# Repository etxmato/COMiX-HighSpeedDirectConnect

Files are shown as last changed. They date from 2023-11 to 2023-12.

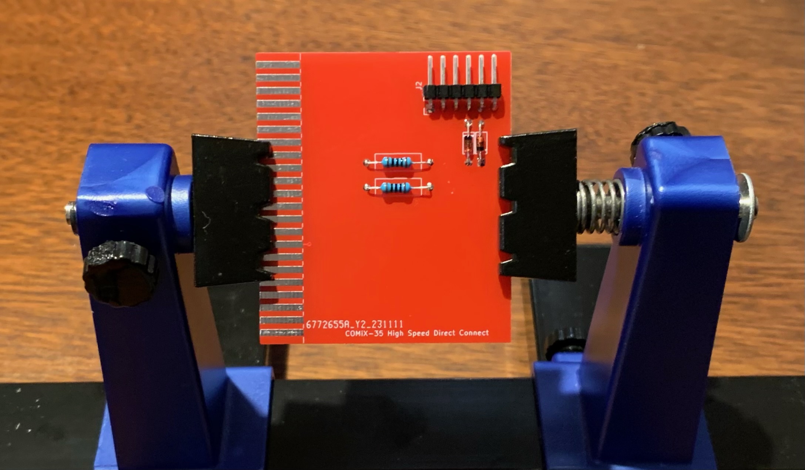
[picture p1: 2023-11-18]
images/HSDC Build.jpeg

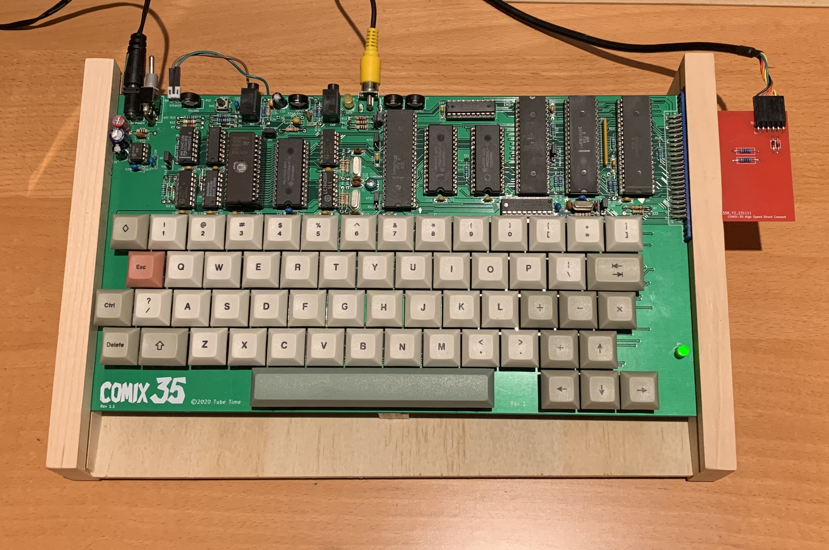
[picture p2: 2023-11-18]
images/COMiX and HSDC Adapter.jpeg

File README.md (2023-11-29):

# COMiX High Speed Direct Connect

With the High Speed Direct Connect HW & SW for the COMiX it is possible to transfer files between a modern PC and a COMiX. On the COMiX, PSAVE and PLOAD commands can be used with speeds of 9600 baud on a 2.8 Mhz CPU and 19200 baud on a 6 Mhz CPU.

Overview of the HSDC solution: 

Comix Direct Connect

Manual and all detailed information is available on our [Wiki](https://github.com/etxmato/COMiX-HighSpeedDirectConnect/wiki)

Andrew Wasson, 
Hank Riley,
Marcel van Tongeren

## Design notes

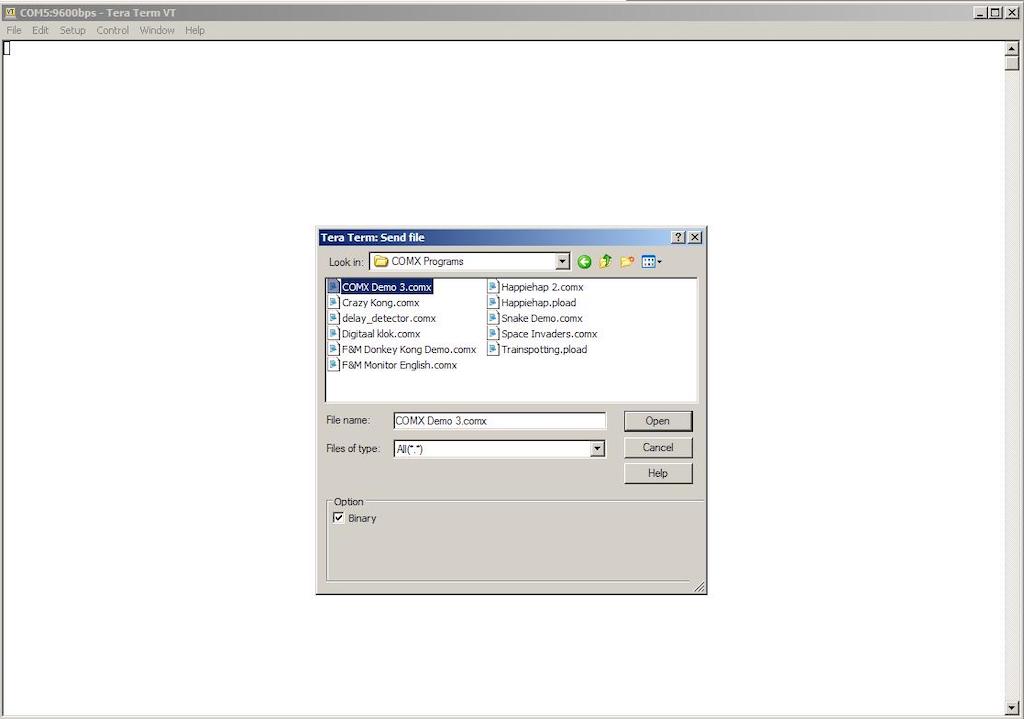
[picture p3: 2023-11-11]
images/teraterm send file as binary COMiX in PLOAD state.jpg

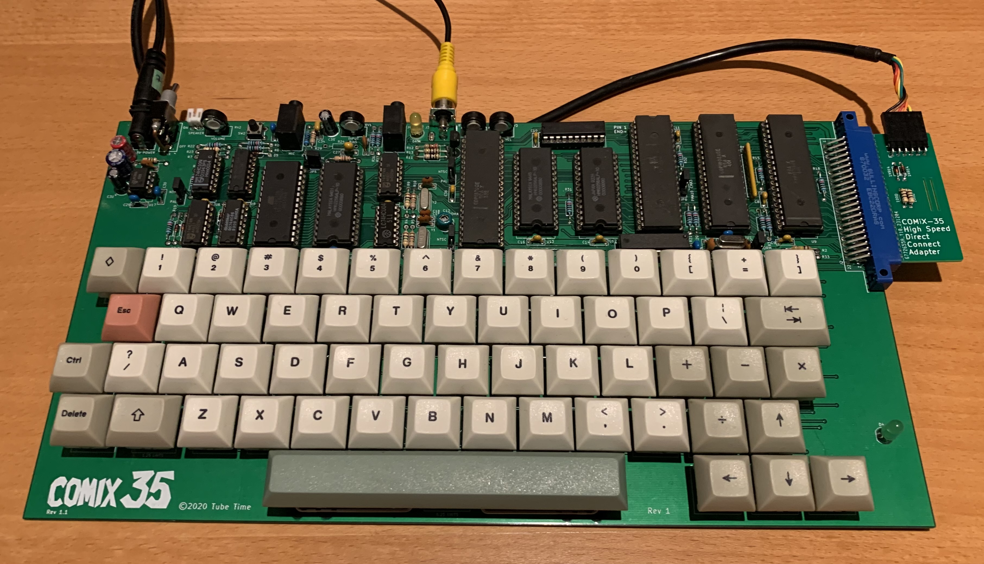
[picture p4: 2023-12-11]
images/IMG_9994-A.jpeg

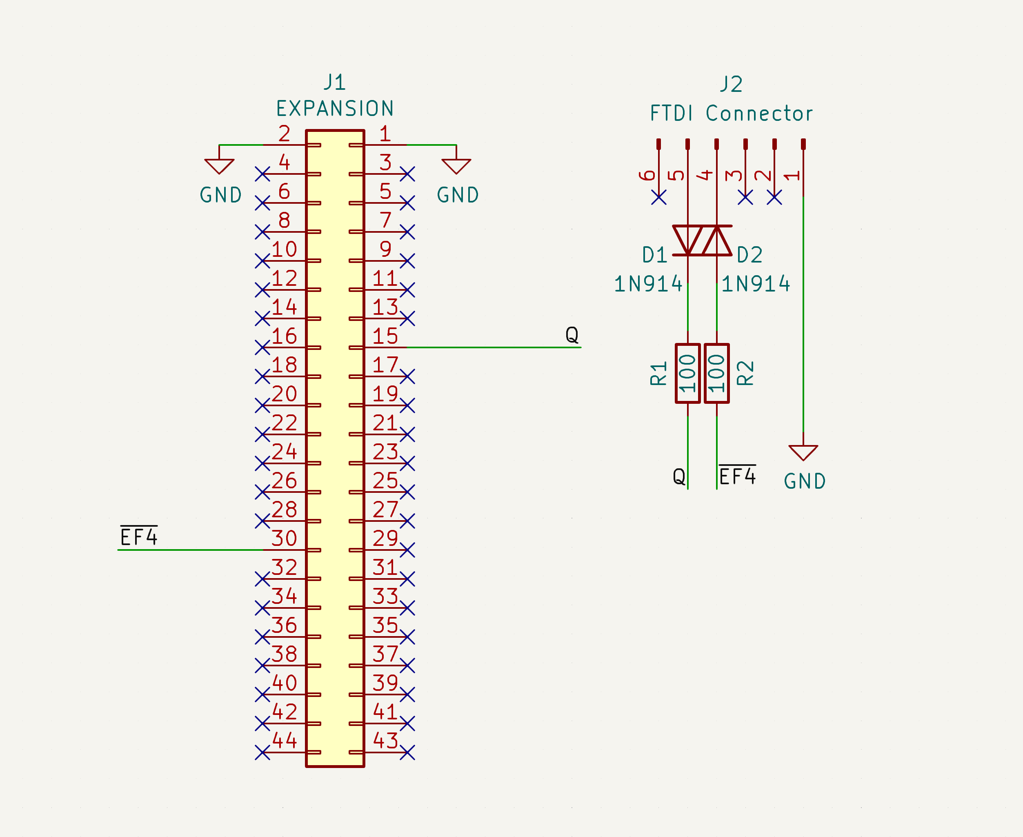
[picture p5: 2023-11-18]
images/COMiX FTDI Adapter Circuit.png

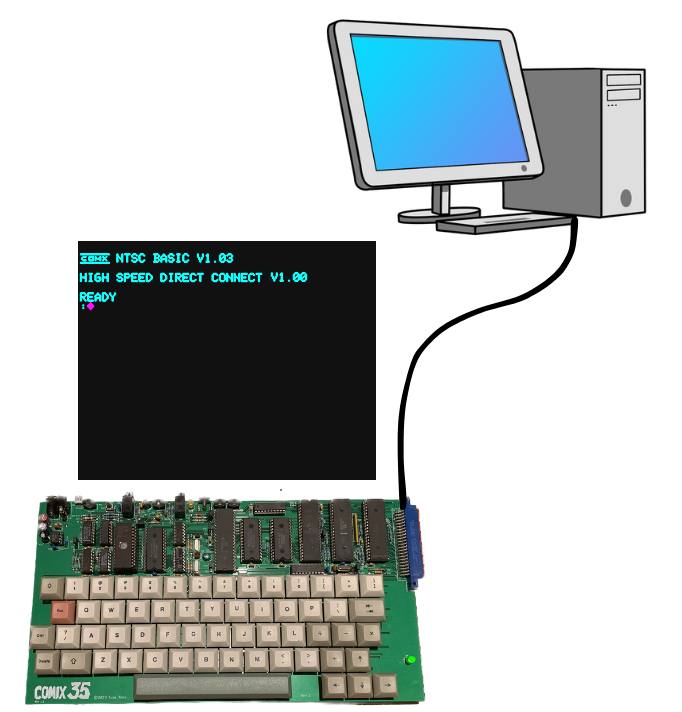
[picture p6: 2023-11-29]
images/overall connection graphic A.jpg

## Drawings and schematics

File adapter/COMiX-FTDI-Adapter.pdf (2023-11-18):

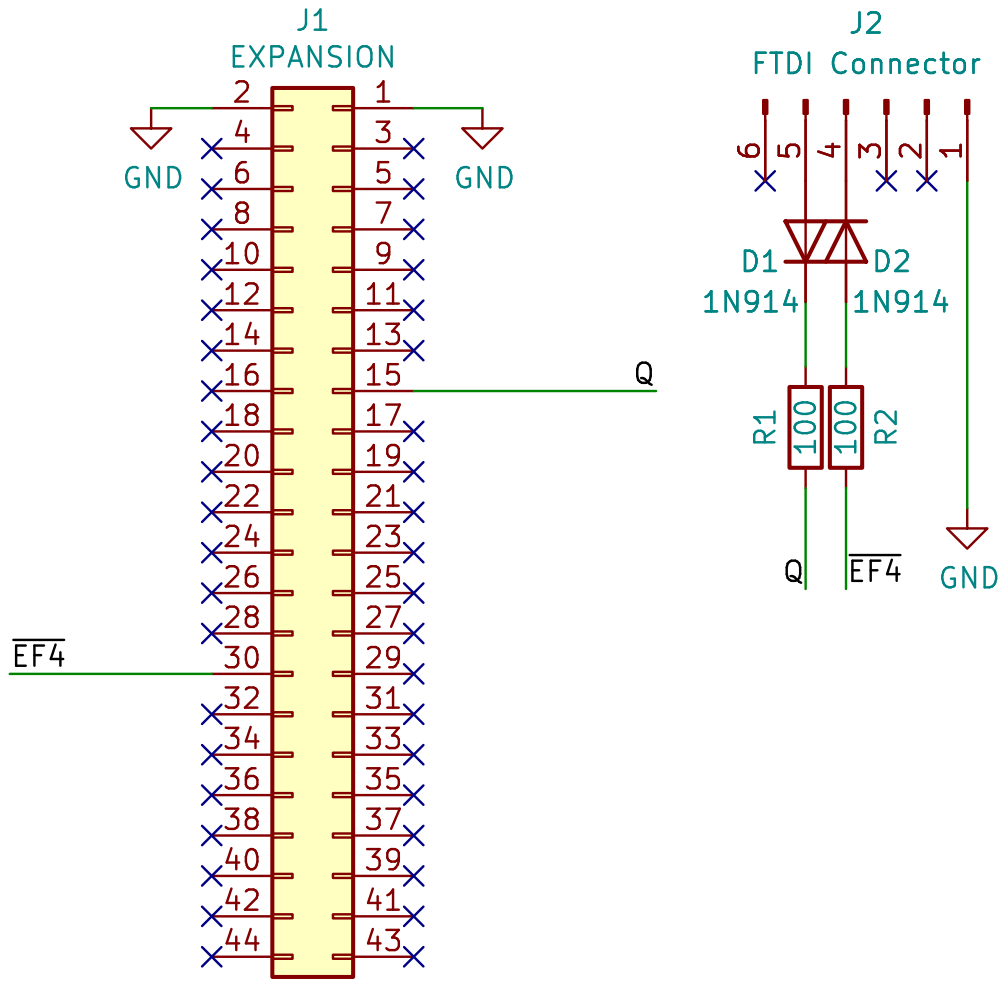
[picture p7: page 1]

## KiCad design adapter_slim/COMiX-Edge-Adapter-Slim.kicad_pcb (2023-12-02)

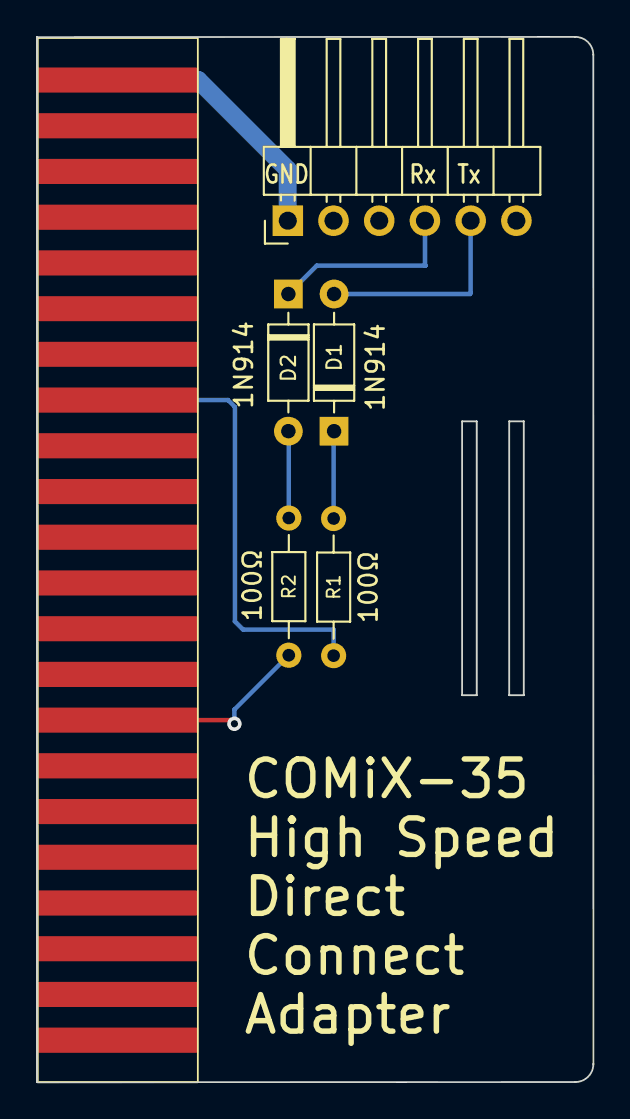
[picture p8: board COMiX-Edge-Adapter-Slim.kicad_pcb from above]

Board: 2 copper layers, 30.9 x 58.1 mm, 6 parts (0 on the bottom side), 7 nets.

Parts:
D1, D2: 1N914; D_DO-35_SOD27_P7.62mm_Horizontal
J1: EXPANSION; Edge_Card_Connector_22x2
J2: FTDI Connector; PinHeader_1x06_P2.54mm_Horizontal
R1, R2: 100Ω; R_Axial_DIN0204_L3.6mm_D1.6mm_P7.62mm_Horizontal

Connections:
/Q: J1.15 (pin), R1.1
/~EF4: J1.30, R2.1
GND: J1.1 (pin), J1.2, J2.1
unnamed: D1.2 (A), J2.5
unnamed: D1.1 (K), R1.2
unnamed: D2.2 (A), R2.2
unnamed: D2.1 (K), J2.4

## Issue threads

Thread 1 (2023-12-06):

Missing Footprint Library

wel97459, 2023-12-06:
Could you include the footprint library that contains the card edge, it would be helpful for other projects.

awasson, 2023-12-06:
Hey Winston,
I just exported and pushed the footprint to the Github repo.

Let me know if you have any trouble with it. It is the first footprint I've created and I need to rename/renumber the footprint conductors because it should have 1-22 on one side and A-Z on the other to match with the COMiX-35 edge connector but I have it alternating 1-44. At some point I plan to update it with the correct 1-22 / A-Z designations but is should save you some effort right off the bat.

Cheers,
Andrew

wel97459, 2023-12-06:
awesome thanks!

wel97459, 2023-12-06:
oops

Closed 2023-12-06.

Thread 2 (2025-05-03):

Serial problems for a future serial cartridge

issalig, 2025-05-03:
Not an issue but a looking for help.

I am working on a project (that will go public when working) that holds an arduino, oled screen, sdcard, and buttons (like arduitape/tapuino)
I just select a file from the sd card and send it through serial 9600 8N1. The idea is to plug it as a cartridge and do not need PC to transfer sw to COMX.

The problem is that I am not able to make it work. On the COMX side I type PLOAD but nothing happens. I have tried with CuteCom under linux and it works. So COMX (really a COMIX clone) hw is working.

Do you know if TeraTerm/CuteCom does some magic I am missing?

The is the arduino code that writes on Serial
```
  for (int i=0; i<sizeof(sample_program); i++) {
    Serial.write(pgm_read_byte(&sample_program[i]));
    delay(10);
  }
```

etxmato, 2025-05-03:
Cool, need to refresh myself a bit… it was a while ago 😜. From what I remember the terminal code just sends the file as you do above.

I just checked my Emma 02 xml file - do you have both EF and Q lines reversed on Arduino side?

etxmato, 2025-05-03:
Can you try without a delay; I see in my development diary that we set Teraterm to use a 0 ms delay.

issalig, 2025-05-03:
Do not think so! I plugged everything usb cable, breadboard mess with arduino and cables to EF, Q and GND.
Then I sent the file with CuteCom (the only special setting is 2ms delay after each sent byte)  and it worked. That means wiring is ok, serial chip from arduino board is receiving it and putting it directly to TX/RX lines  that are the connected to EF, Q with diodes and resistors as in your pcb.

I will try to adjust the delay and also have a look at the xml file.

Thanks for your fast answer.

etxmato, 2025-05-03:
I have this in my xml file:
        <ef pol="rev">4</ef>
        <q pol="rev"></q>

Meaning they should be reversed somehow in the Arduino code as well otherwise it might not work. I don't know if/how CuteCom does that.

issalig, 2025-05-04:
After plugging the logic analyzer I have realised that wieres exiting from TX/RX from arduino where reversed :) .

Now it is working in Arduino. Hope to have a beta version soon.

issalig, 2025-05-04:
Also one more question. I want to record the program by reading the bytes from serial after a "PSAVE".
I could do it without knowing the COMX file format but I guess it is better to know the format and thus the know the size of the program.
I have been searching in emma code but I do not find this info.
Any hint?

issalig, 2025-05-04:
After some reverse engineering I found that byte[10]+6 has the file size at least in BASIC programs.

```
//total size array is 47
//size can be computed as byte [10] + 6
 unsigned char sample_program [] /*PROGMEM*/ = {
 0x06,
 0x43, 0x4f, 0x4d, 0x58, // header "COMX"
 0x00, 0x0c,
 0x00, 0x20, // size info 0x20 is 32
 0x00, 0x29, // size info 0x29 is 41, byte [41] is before 0xff 0xff marker
 0x00, 0x29,
 0x00, 0x29,
 0x00, 0x00, 0x20,
 0x00, 0x00, 0x00, 0x00, 0x00, 0x00, 0x00, 0x00, 0x00,
 // BASIC program 10 PRINT "COMIXINO"
 0x00, // beginning of line
 0x0a, // line number 10
 0x0d, // line length 13
 0x86, // Token for PRINT
 0xcf, // Token for string beginning
 0x43, 0x4f, 0x4d, 0x49, 0x58, 0x49, 0x4e, 0x4f, // COMIXINO string
 0xce, // Token for string end
 0x0d, //end of line
 0xff, 0xff,
 0x03, 0x84,
 0x0d //final terminator
 };
``

etxmato, 2025-05-04:
First byte 1 format is a bit simpler:

Byte 1-4: as you state COMX
Byte 5-6: start address
Byte 7-8: end address
Byte 9-10: execution address

There are also a few more formats, first byte:
2 - old BASIC format, replaced by 6
3 - format for use with F&M BASIC
4 - old data format, this one was faulty
5 - data save (Byte 1-2 CO, Byte 3/4 data length, 5/6 array length

issalig, 2025-05-06:
PCB's ordered. I will upload the files once are checked. Still working in the recording function but almost fixed.

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

issalig, 2025-06-04:
Some progress. Now I have a working SW and HW (with some bodge wires :) )

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

I am checking everything before release candidate and I see that in your circuit (as well as mine because I shamelessly copied it) after EF4 there is resistor and a diode pointing outwards but it is working as RX.
The same for Q but inwards and and TX.

I have some background in electronics but not an expert and I do not understand how EF4 receives data given that a diode blocks everything. Any hint?

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

issalig, 2025-06-30:
Comixino is finally released

https://github.com/issalig/comix35/tree/main/comixino
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

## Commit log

2023-11-18 add adapter card files
    [COMiX-FTDI-Adapter-B_Cu.gbl, COMiX-FTDI-Adapter-B_Mask.gbs, COMiX-FTDI-Adapter-B_Paste.gbp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]
2023-11-20 Remove .DS_Store from current directory
2023-11-30 update edge connector with curved edges
    [COMiX-FTDI-Adapter-B_Cu.gbl, COMiX-FTDI-Adapter-B_Mask.gbs, COMiX-FTDI-Adapter-B_Paste.gbp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]
2023-12-02 add adapter slim image, working files and gerbers
    [COMiX-Edge-Adapter-Slim-B_Cu.gbl, COMiX-Edge-Adapter-Slim-B_Mask.gbs, COMiX-Edge-Adapter-Slim-B_Paste.gbp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]
2023-12-06 add custom edge connector footprint
2023-12-11 New Edge Card PCB Images
2023-12-11 New Edge Card PCB Image
2023-12-11 Better Edge Card PCB Image
